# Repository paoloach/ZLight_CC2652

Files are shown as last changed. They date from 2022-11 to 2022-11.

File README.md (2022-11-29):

# ZLight_CC2652
A light and a PIR handled by Zigbee

The firmware is made for a CC2652RB and CC2652P TI chips and it is avaiable under the firmware folder.
The first version was for E72-2G4M05S1F (CC2652RB) module but for his shortage, I migrated to the E72-2G4M05S1E module, based on CC2652P1F chip.

For licence issue, I can't put the sources, but you can request at me (pachdjian@gmail.com)

Into firmware folder there are both the firmware.
Into Box, there is a Freecad model for a box I made
Into Schematic thare is two versions on a KiCad circuit with a PCB layout. 
 * The first version is for a E72-2G4M05S1F and it is without a PIR connector.
 * The second version is for a E72-2G4M05S1E module, it contains some fixes and enanchements 

# Instruction

The power supply is 12 Volts. The maximum limits is set by the LM1117 chip that has a maximum input value of 15 Volts.
The PIR used is a AS312, but there are a plenty of others PIR sensors. The important thing is that it should be power by 3.3 volt and a digital output.

The consume is about 0.4 - 0.5 A, so the maximum  emitted light is about 5-6 Watt.
It implement a On/Off and Controll cluster, so you can reduce the luminosity.

The first time the ZLight start it search for a available network.
The two leds blink alternately.

If you need to reset the network, press button 1 for more that 5 seconds.

Then the ZLight will be reset the network configuration and it will begin to search for a new network, blinking the two leds

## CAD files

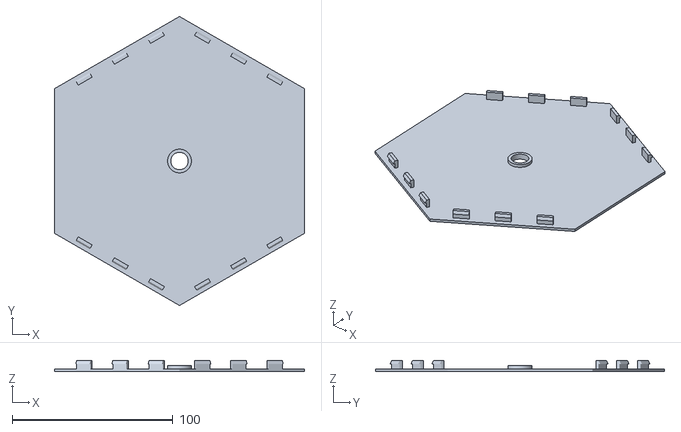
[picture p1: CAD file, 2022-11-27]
Box/Freecad/ZLigth-Coperchio.stl
155.9 x 180.0 x 6.80

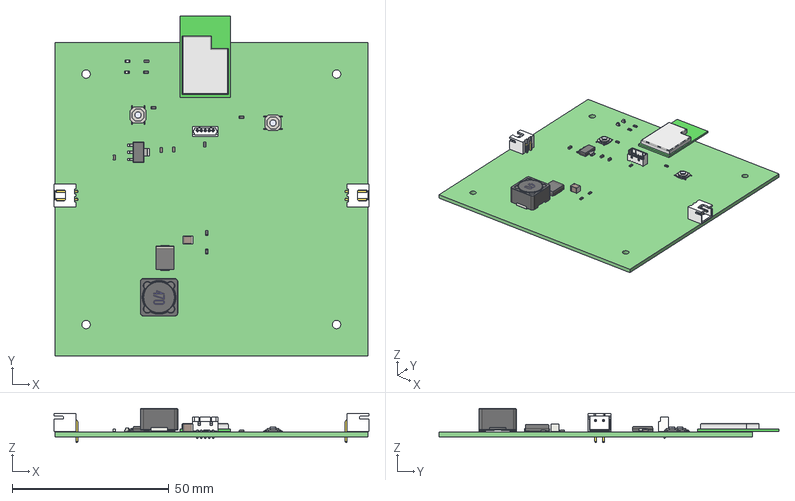
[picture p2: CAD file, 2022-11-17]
Schematic/ZLight_V2/ZLight_V2.step
100.6 x 108.5 x 10.9 mm
ZLight PCB

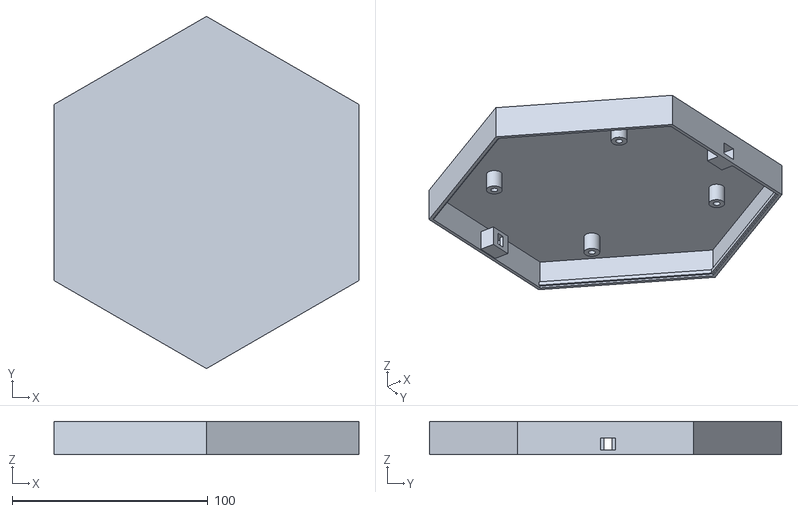
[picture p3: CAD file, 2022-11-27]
Box/Freecad/ZLigth-Body.stl
155.9 x 180.0 x 17.0

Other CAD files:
Box/Freecad/ZLigth.FCStd

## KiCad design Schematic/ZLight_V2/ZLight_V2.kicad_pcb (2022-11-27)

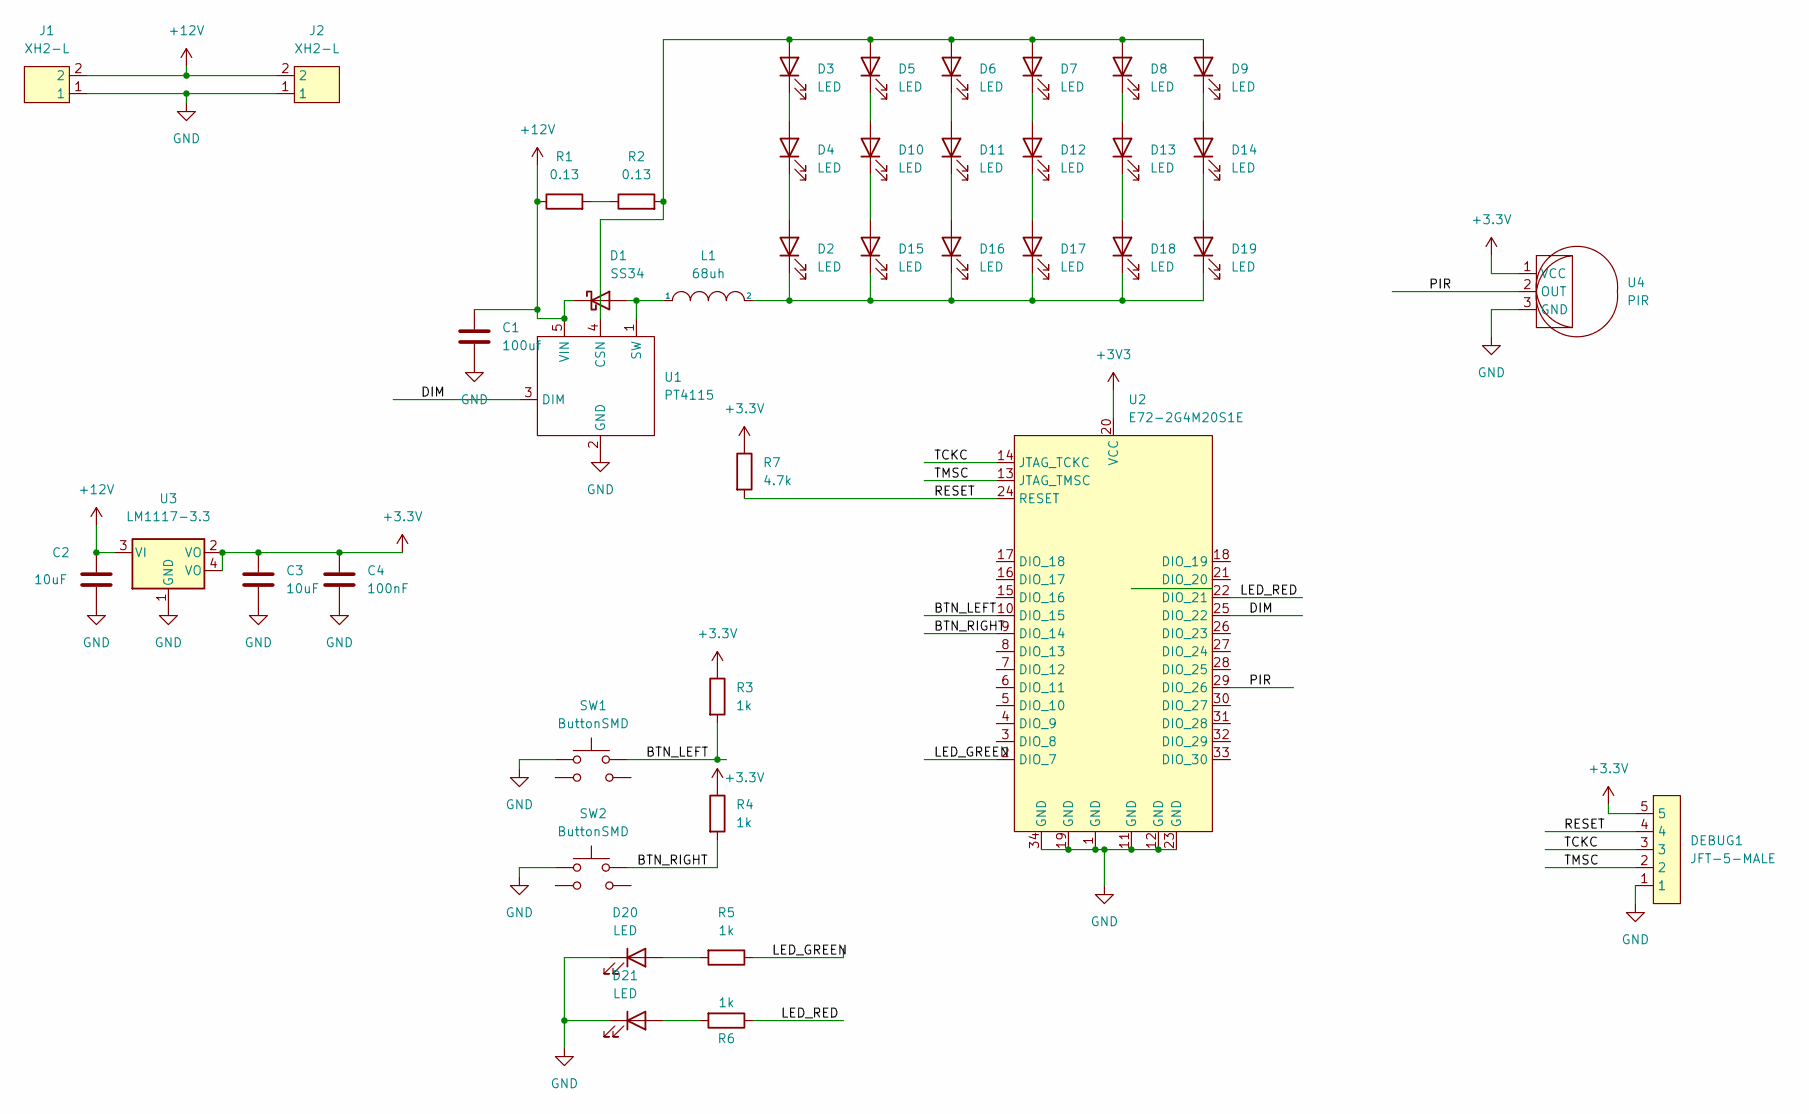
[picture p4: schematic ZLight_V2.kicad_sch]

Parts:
C1: 100uf; C_1210_3225Metric_Pad1.33x2.70mm_HandSolder
C2, C3: 10uF; C_0603_1608Metric_Pad1.08x0.95mm_HandSolder
C4: 100nF; C_0603_1608Metric_Pad1.08x0.95mm_HandSolder
D1: SS34
D2, D3, D4, D5, D6, D7, D8, D9, D10, D11, D12, D13, D14, D15, D16, D17, D18, D19: LED; LED_Yuji_5730
D20, D21: LED; LED_0603_1608Metric_Pad1.05x0.95mm_HandSolder
DEBUG1: JFT-5-MALE; XH5-V
J1, J2: XH2-L; XH2-H
L1: 68uh; RH127
R1, R2: 0.13; R_0603_1608Metric_Pad0.98x0.95mm_HandSolder
R3, R4, R5, R6: 1k; R_0603_1608Metric_Pad0.98x0.95mm_HandSolder
R7: 4.7k; R_0603_1608Metric_Pad0.98x0.95mm_HandSolder
SW1, SW2: ButtonSMD
U1: PT4115; SOT-89-5_Handsoldering
U2: E72-2G4M20S1E
U3: LM1117-3.3; SOT-223
U4: PIR; XH3-V

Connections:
+12V: C1.1, C2.1, D1.1 (K), J1.2, J2.2, R1.1, U1.5 (VIN), U3.3 (VI)
/BTN_LEFT: R3.2, SW1.2, U2.10 (DIO_15)
/BTN_RIGHT: R4.2, SW2.2, U2.9 (DIO_14)
/DIM: U1.3 (DIM), U2.25 (DIO_22)
/LED_GREEN: R5.1, U2.2 (DIO_7)
/LED_RED: R6.1, U2.22 (DIO_21)
/PIR: U2.29 (DIO_26), U4.2 (OUT)
/RESET: DEBUG1.4, R7.2, U2.24 (RESET)
/TCKC: DEBUG1.3, U2.14 (JTAG_TCKC)
/TMSC: DEBUG1.2, U2.13 (JTAG_TMSC)
GND: C1.2, C2.2, C3.2, C4.2, D20.1 (K), D21.1 (K), DEBUG1.1, J1.1, J2.1, SW1.1, SW2.1, U1.2 (GND), U2.1 (GND), U2.11 (GND), U2.12 (GND), U2.19 (GND), U2.23 (GND), U2.34 (GND), U3.1 (GND), U4.3 (GND)
unnamed: D1.2 (A), L1.1, U1.1 (SW)
unnamed: D2.2 (A), D4.1 (K)
unnamed: D3.1 (K), D4.2 (A)
unnamed: D3.2 (A), D5.2 (A), D6.2 (A), D7.2 (A), D8.2 (A), D9.2 (A), R2.2, U1.4 (CSN)
unnamed: D10.1 (K), D15.2 (A)
unnamed: D5.1 (K), D10.2 (A)
unnamed: D11.1 (K), D16.2 (A)
unnamed: D6.1 (K), D11.2 (A)
unnamed: D12.1 (K), D17.2 (A)
unnamed: D7.1 (K), D12.2 (A)
unnamed: D13.1 (K), D18.2 (A)
unnamed: D8.1 (K), D13.2 (A)
unnamed: D14.1 (K), D19.2 (A)
unnamed: D9.1 (K), D14.2 (A)
unnamed: D2.1 (K), D15.1 (K), D16.1 (K), D17.1 (K), D18.1 (K), D19.1 (K), L1.2
unnamed: D20.2 (A), R5.2
unnamed: D21.2 (A), R6.2
unnamed: R1.2, R2.1

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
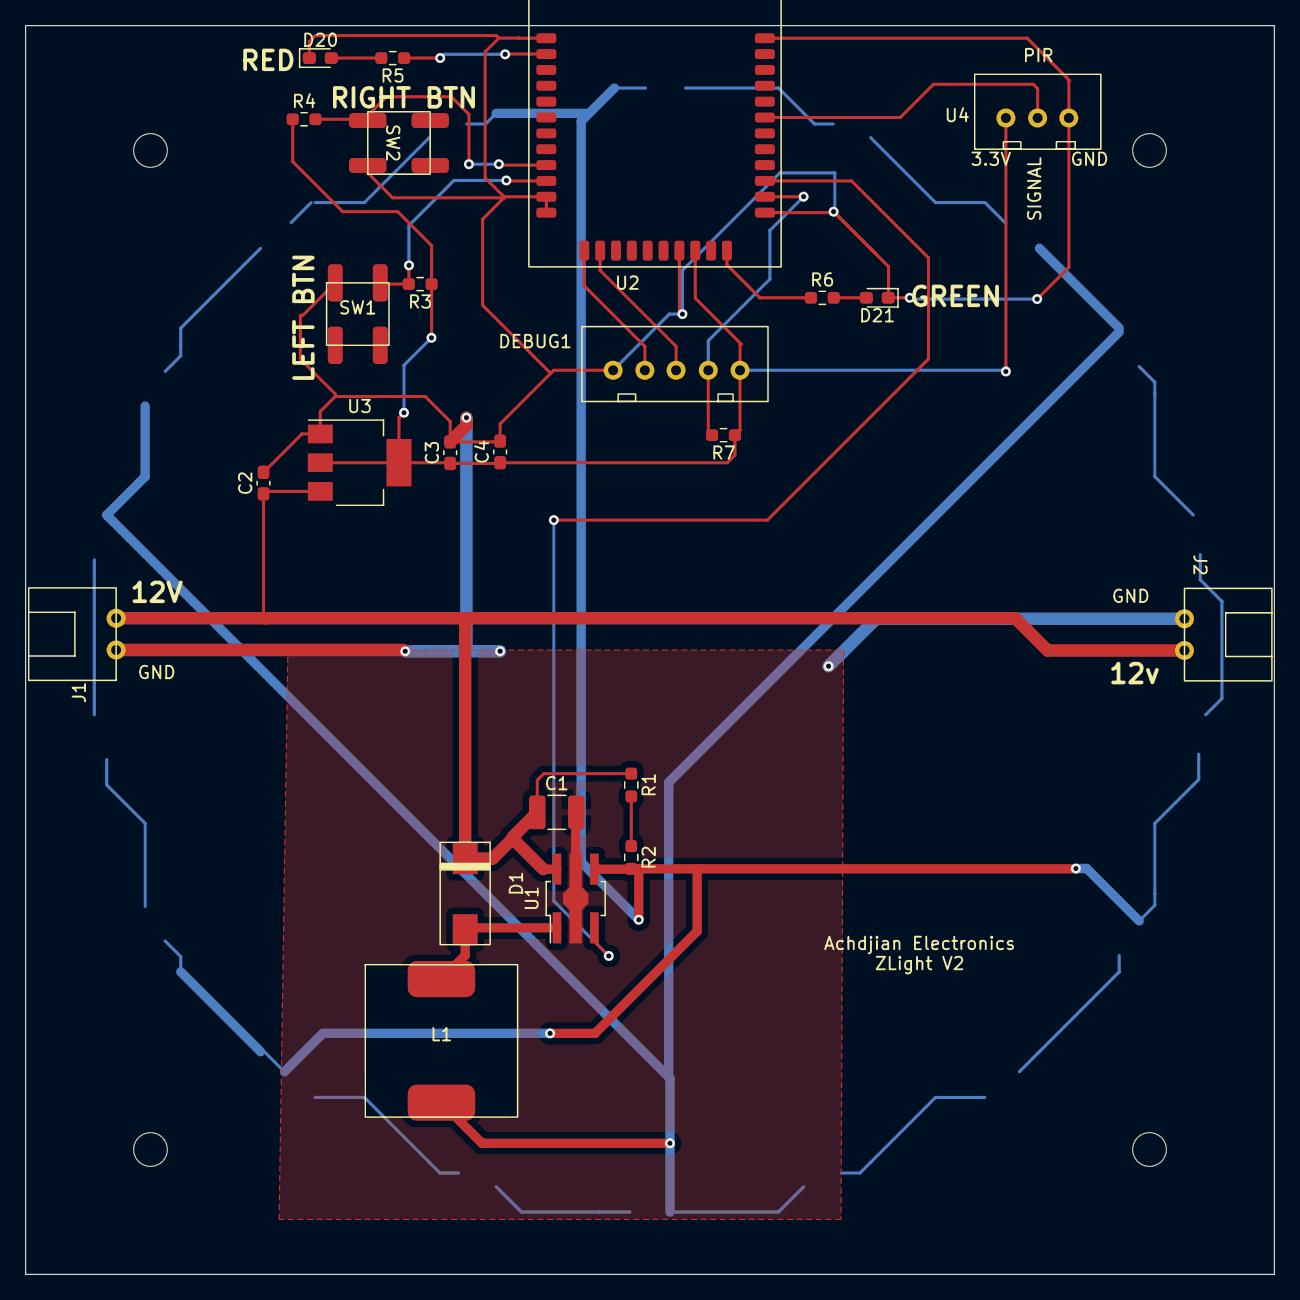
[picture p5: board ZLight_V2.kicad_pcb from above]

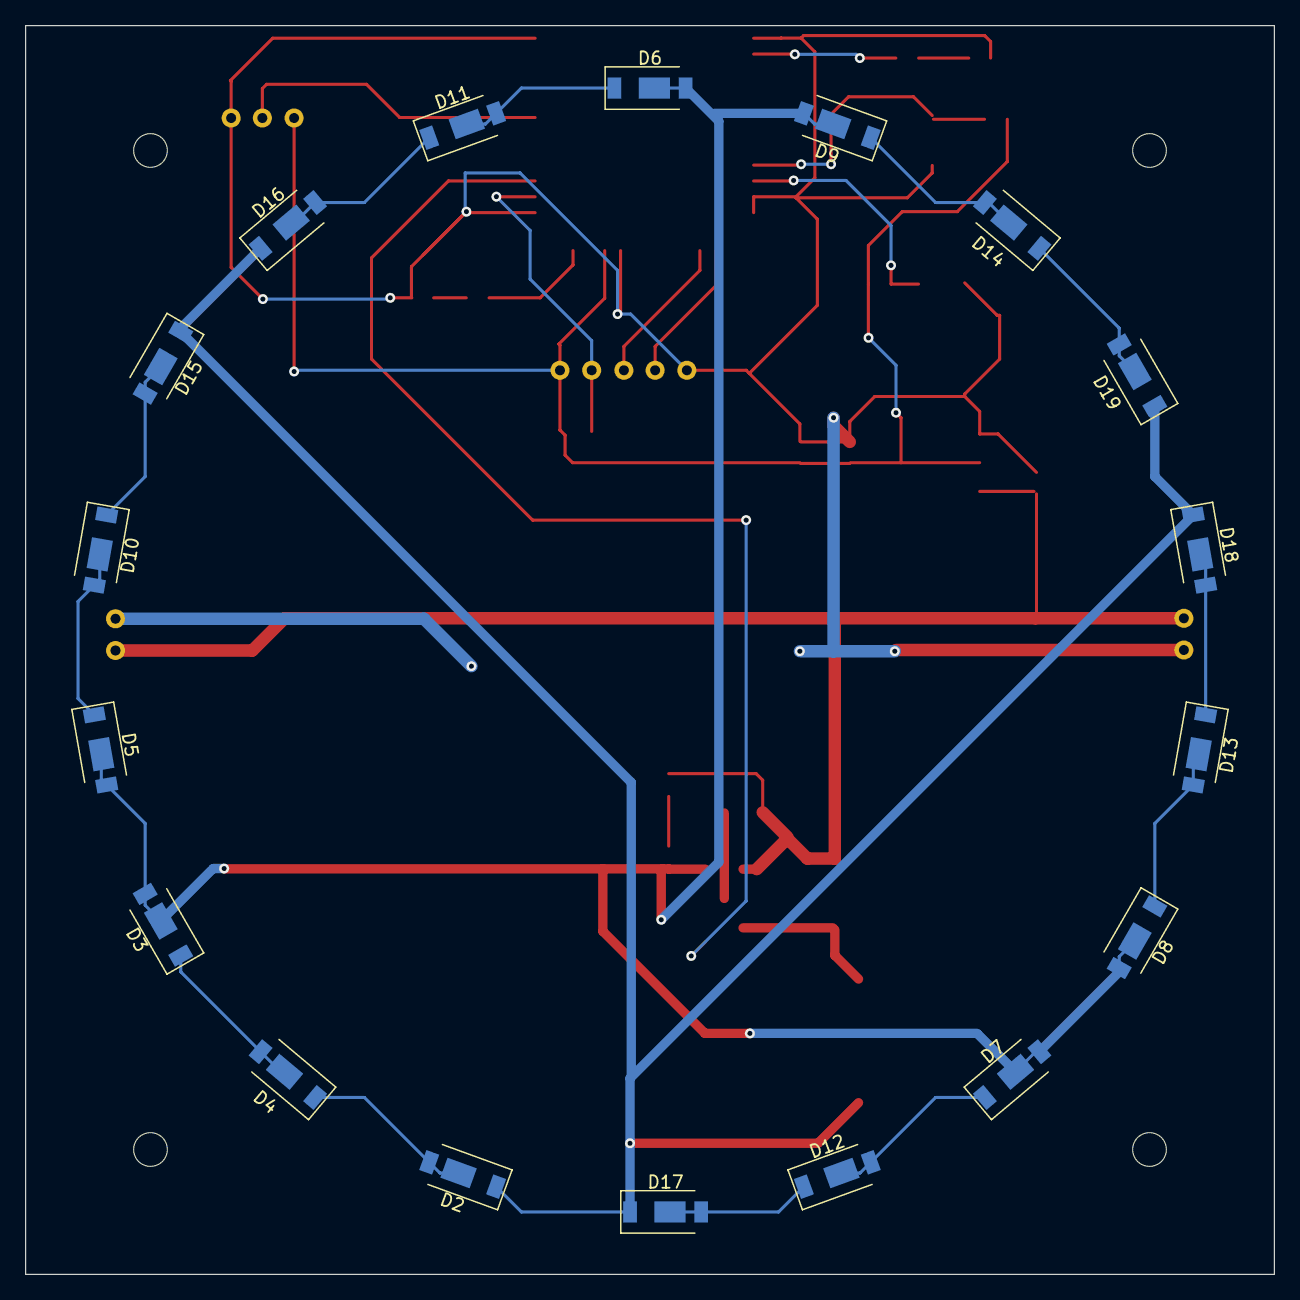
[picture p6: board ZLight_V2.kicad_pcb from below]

Board: 2 copper layers, 100.0 x 100.0 mm, 42 parts (18 on the bottom side), 30 nets.
